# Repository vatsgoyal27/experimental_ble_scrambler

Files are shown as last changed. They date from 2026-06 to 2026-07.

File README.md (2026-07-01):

# BLE Experimental FHSS Test Platform

An experimental multi-radio platform built around the **nRF24L01+** for investigating frequency hopping behavior across the 2.4 GHz ISM band.

> **Disclaimer**
>
> This project is intended solely for laboratory testing, RF characterization, and educational purposes inside controlled environments. It is **not** intended for interfering with wireless communications or transmitting on frequencies in violation of local regulations.

---

## Overview

This board contains:

- Raspberry Pi Pico W controller
- Three independent nRF24L01+ transceivers
- Three external RF power amplifiers
- Individual RF filtering stages
- SMA antenna connectors for each RF chain

The objective is to create a configurable RF test platform capable of:

- Continuous carrier generation
- Channel sweeping
- Experimental frequency hopping
- Timing analysis
- Multi-radio synchronization
- BLE advertising channel experiments

---

## Hardware

### Controller

- Raspberry Pi Pico W
- 3.3 V logic

### RF Chain (×3)

Each RF path contains:

```
Pico SPI
      │
      ▼
nRF24L01+
      │
      ▼
2.45 GHz RF Filter
      │
      ▼
RF2401C Power Amplifier
      │
      ▼
2450LP14A100T Matching Network
      │
      ▼
SMA Connector
```

Each radio has:

- Dedicated 16 MHz crystal
- Local decoupling
- Separate CE control
- Shared SPI bus
- Individual RF output chain

---

## Schematic

The design currently consists of three identical RF sections driven from a common SPI interface.

Features include:

- SPI shared between all radios
- Independent CE lines
- External RF front-end
- Matching network
- Filtered antenna output

---

## Current Firmware

Current firmware configures an nRF24L01+ as:

- Transmitter mode
- Auto ACK disabled
- CRC disabled
- 2 Mbps
- Maximum PA level
- Constant carrier enabled

Example initialization:

```cpp
radio.setAutoAck(false);
radio.stopListening();
radio.setRetries(0,0);
radio.setPayloadSize(5);
radio.setAddressWidth(3);
radio.setPALevel(RF24_PA_MAX);
radio.setDataRate(RF24_2MBPS);
radio.setCRCLength(RF24_CRC_DISABLED);

radio.startConstCarrier(RF24_PA_MAX, channel);
```

---

## Experimental Channel Sweep

The current proof-of-concept changes the RF channel by repeatedly calling

```cpp
radio.setChannel(channel);
```

Example sweep:

```cpp
for (int i = 0; i < 79; i++)
{
    radio.setChannel(i);
}
```

---

## BLE Advertising Channel Test

The firmware also demonstrates hopping across the three BLE advertising channels.

```cpp
byte ble_channels[] =
{
    37,
    38,
    39
};

for(int i=0;i<3;i++)
{
    radio.setChannel(ble_channels[i]);
}
```

This serves as a simple experiment in channel switching behavior rather than implementing the Bluetooth Low Energy protocol itself.

---

## Project Goals

- [x] Multi-radio PCB
- [x] External PA integration
- [x] RF filtering
- [x] Basic firmware
- [x] Constant carrier generation
- [x] Channel switching
- [ ] Precise timing control
- [ ] Simultaneous multi-radio hopping
- [ ] DMA-driven SPI control
- [ ] RP2040 PIO synchronization
- [ ] Measurement using SDR
- [ ] Spectrum characterization

---

## Requirements

### Hardware

- Raspberry Pi Pico W
- 3 × nRF24L01+
- RF2401C
- 2450LP14A1002T filter
- 3.3 V power supply
- Antennas or appropriate RF loads for testing

### Software

- Arduino IDE
- RF24 library
- Raspberry Pi Pico board package

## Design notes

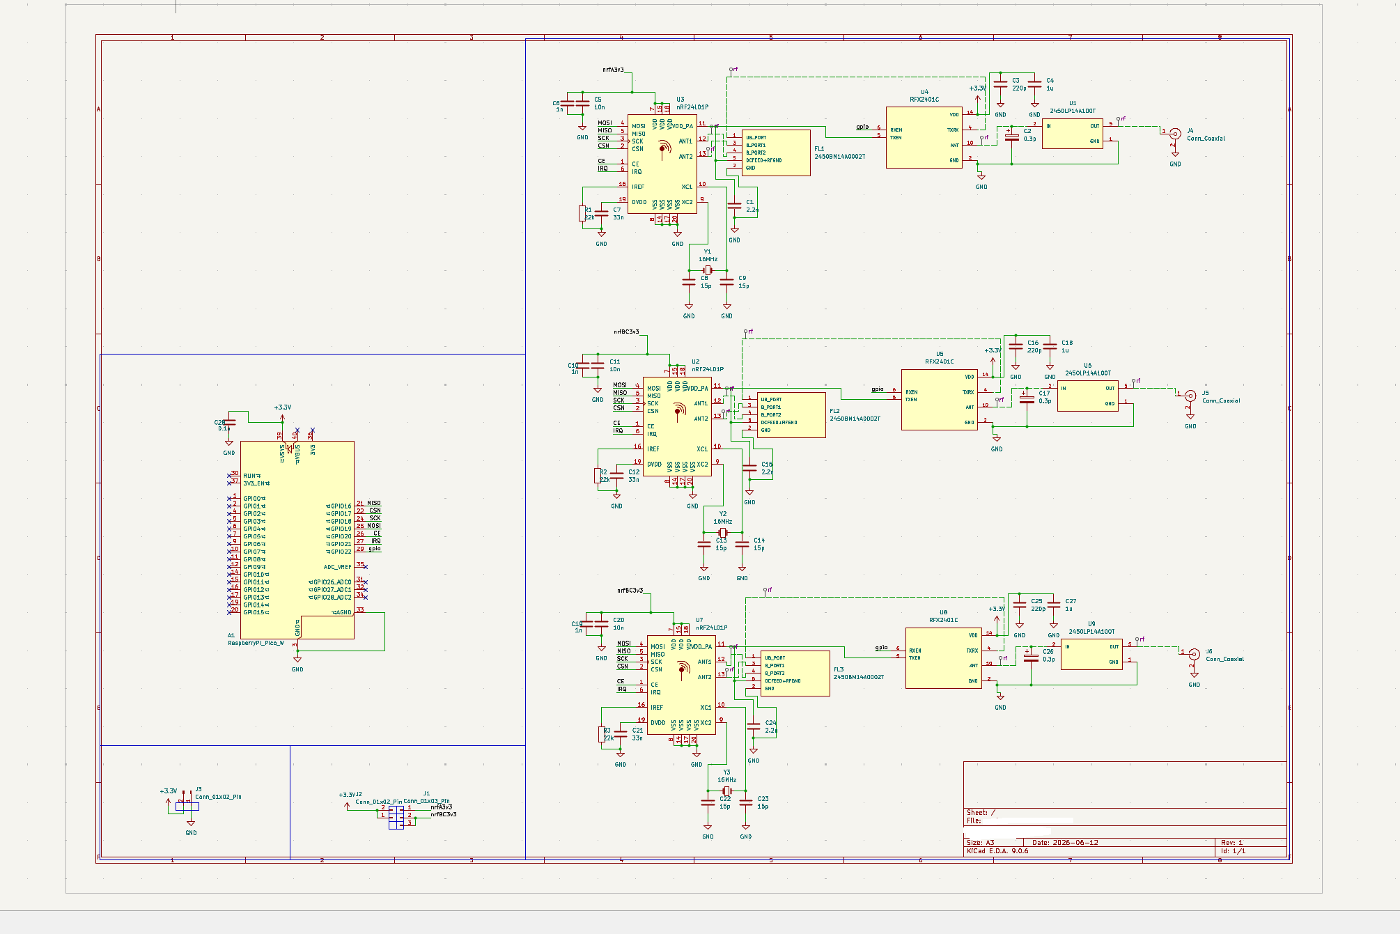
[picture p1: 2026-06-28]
ble_blocker_holder/schematic.png

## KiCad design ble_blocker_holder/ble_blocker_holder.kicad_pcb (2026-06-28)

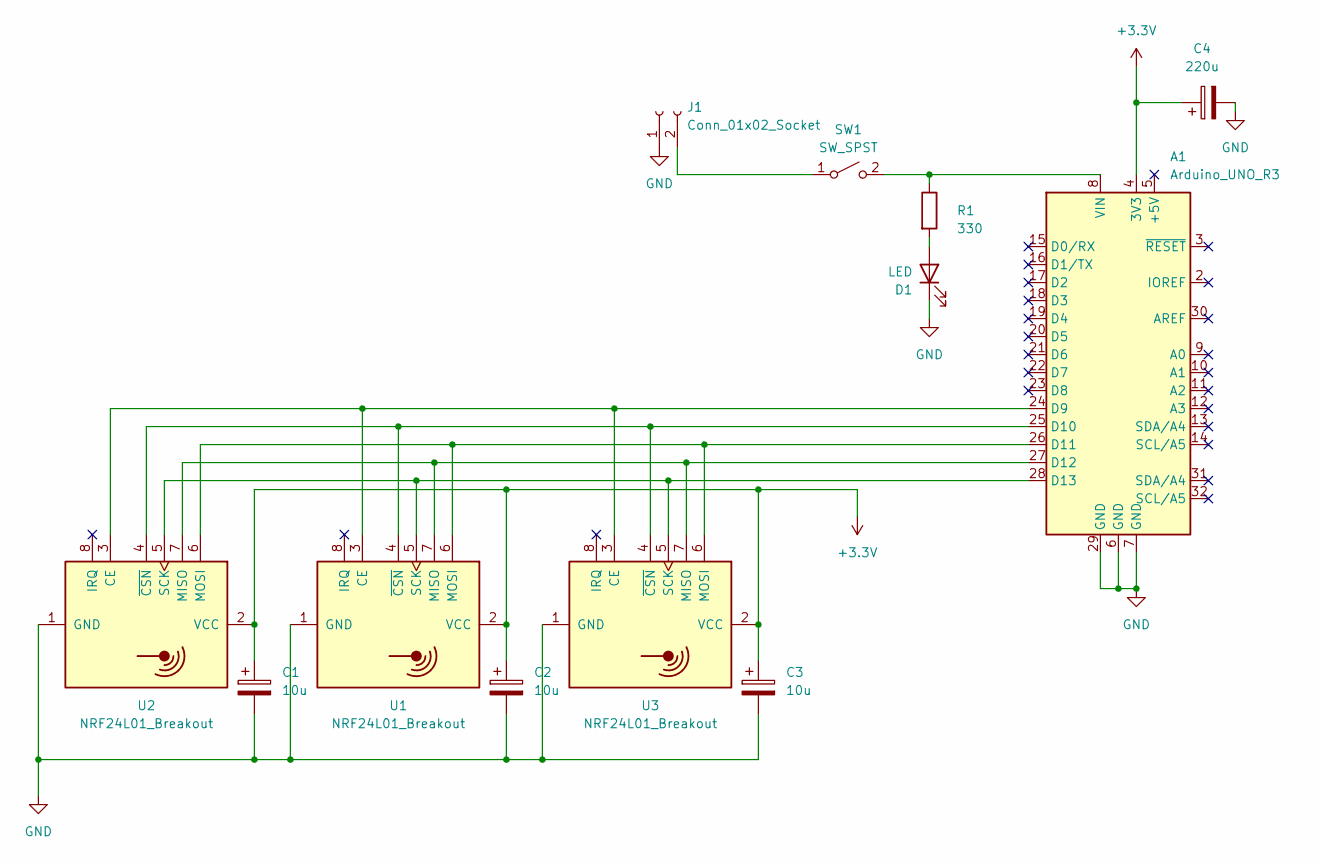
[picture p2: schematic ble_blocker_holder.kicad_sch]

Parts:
A1: Arduino_UNO_R3
C1, C2, C3: 10u; CP_Radial_D10.0mm_P2.50mm
C4: 220u; CP_Radial_D12.5mm_P5.00mm
D1: LED; LED_D5.0mm
J1: Conn_01x02_Socket; PinSocket_1x02_P2.54mm_Vertical
R1: 330; R_Axial_DIN0207_L6.3mm_D2.5mm_P7.62mm_Horizontal
SW1: SW_SPST; SW_DIP_SPSTx01_Slide_9.78x4.72mm_W7.62mm_P2.54mm
U1, U2, U3: NRF24L01_Breakout; nRF24L01_Breakout

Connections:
+3.3V: A1.4 (3V3), C1.1, C2.1, C3.1, C4.1, U1.2 (VCC), U2.2 (VCC), U3.2 (VCC)
GND: A1.6 (GND), A1.7 (GND), A1.29 (GND), C1.2, C2.2, C3.2, C4.2, D1.1 (K), J1.1, U1.1 (GND), U2.1 (GND), U3.1 (GND)
unnamed: A1.24 (D9), U1.3 (CE), U2.3 (CE), U3.3 (CE)
unnamed: A1.25 (D10), U1.4 (~CSN), U2.4 (~CSN), U3.4 (~CSN)
unnamed: A1.26 (D11), U1.6 (MOSI), U2.6 (MOSI), U3.6 (MOSI)
unnamed: A1.27 (D12), U1.7 (MISO), U2.7 (MISO), U3.7 (MISO)
unnamed: A1.28 (D13), U1.5 (SCK), U2.5 (SCK), U3.5 (SCK)
unnamed: A1.8 (VIN), R1.1, SW1.2 (B)
unnamed: D1.2 (A), R1.2
unnamed: J1.2, SW1.1 (A)

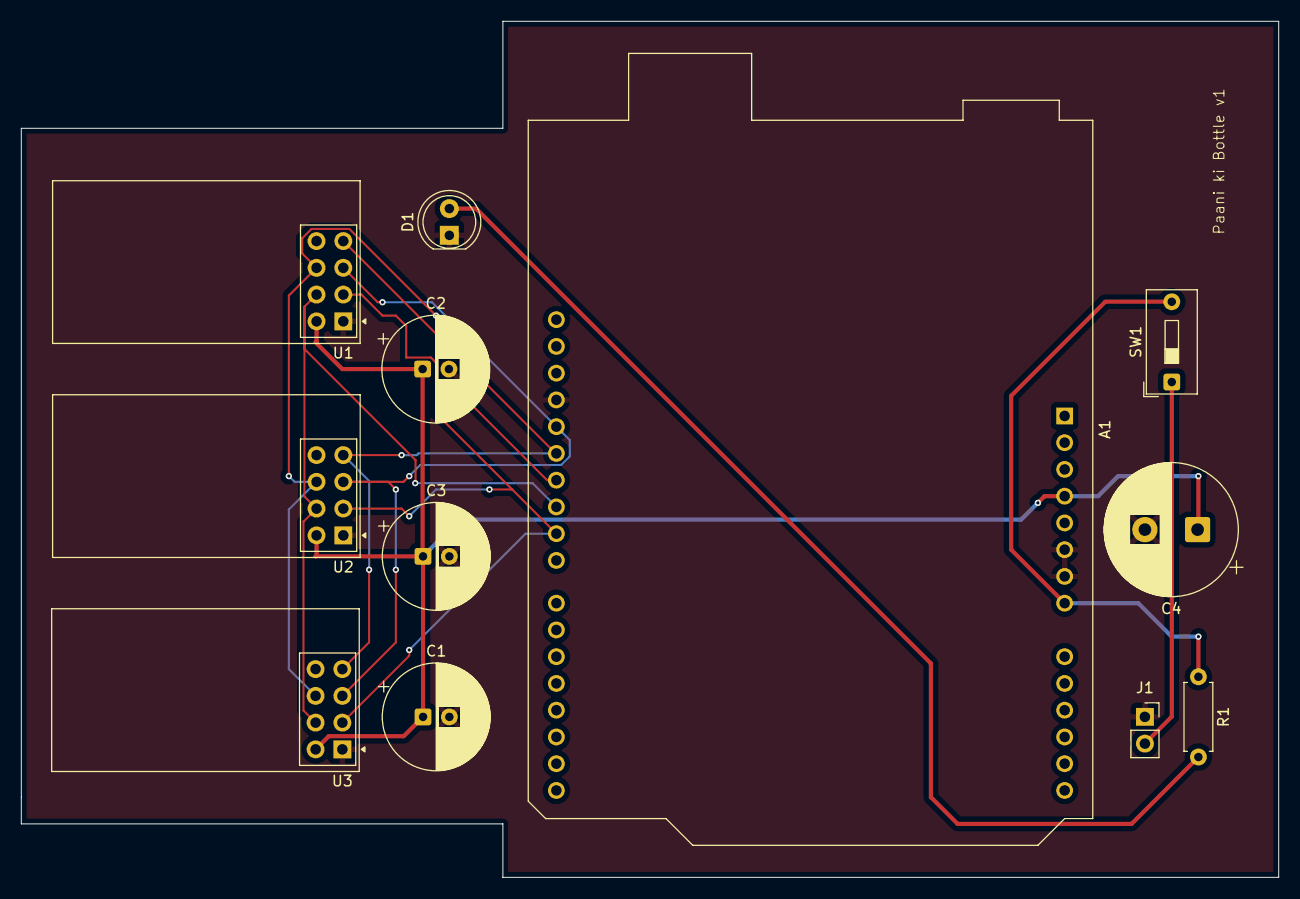
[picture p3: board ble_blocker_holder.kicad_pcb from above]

Board: 2 copper layers, 119.4 x 81.3 mm, 12 parts (0 on the bottom side), 10 nets.

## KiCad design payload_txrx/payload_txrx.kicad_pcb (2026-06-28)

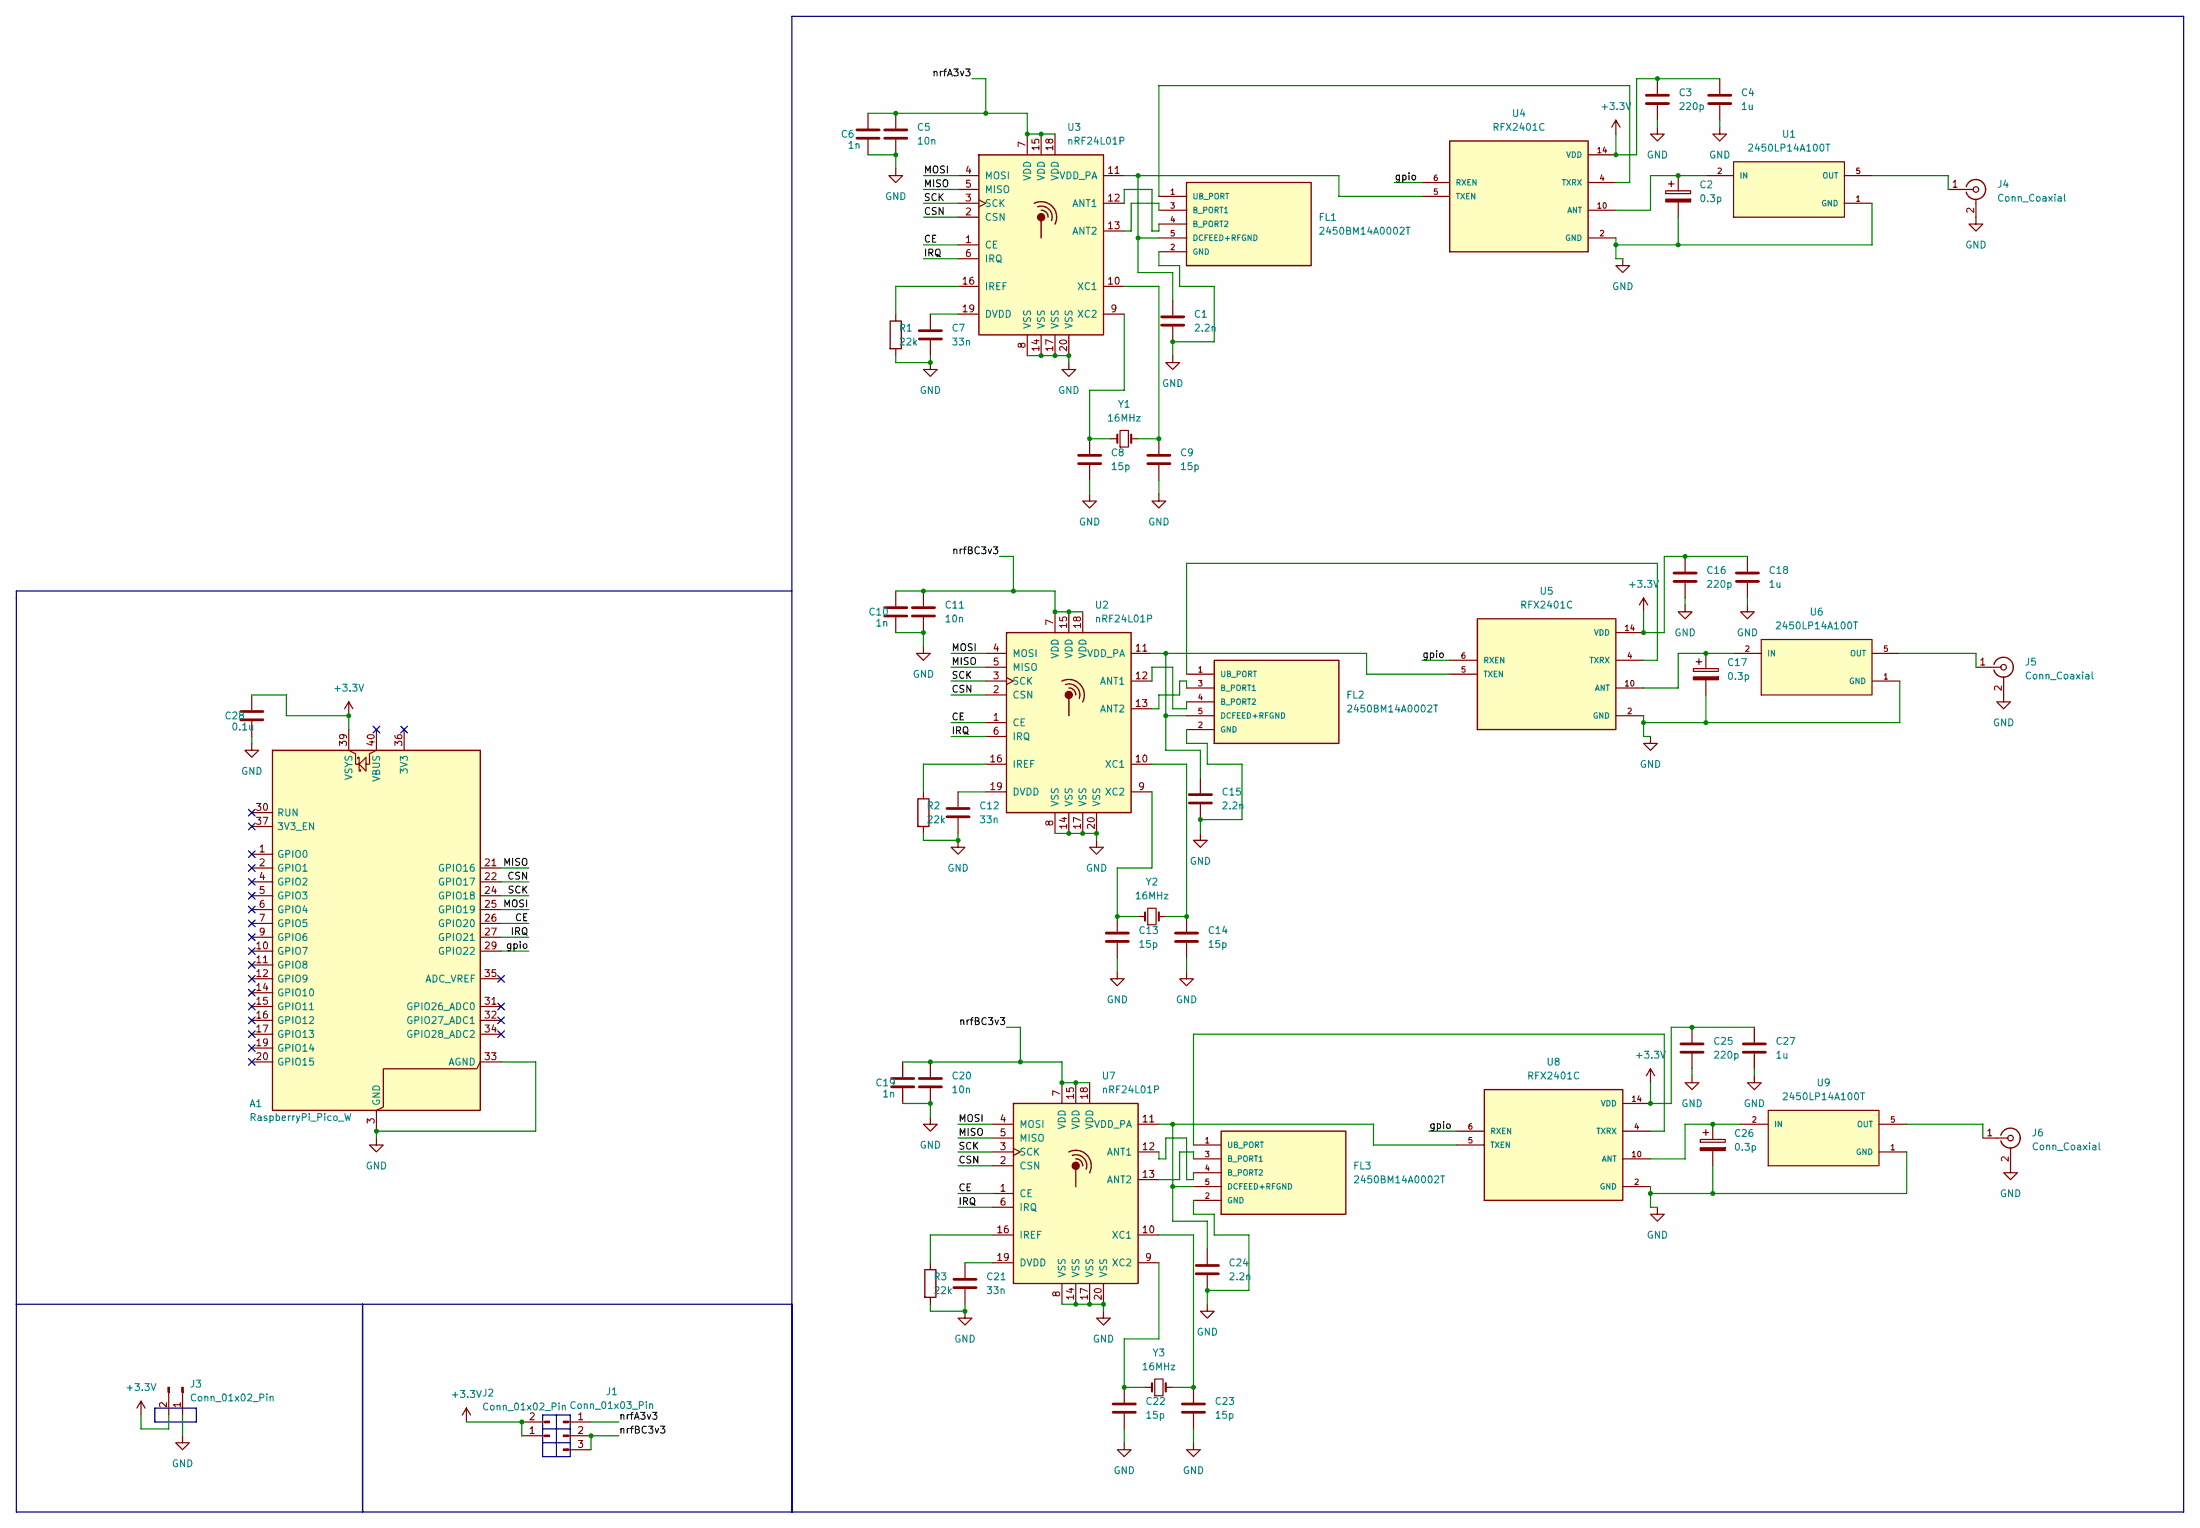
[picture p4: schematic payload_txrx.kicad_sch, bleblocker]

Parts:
A1: RaspberryPi_Pico_W; RaspberryPi_Pico_W_SMD_HandSolder
C1, C15, C24: 2.2n; C_0402_1005Metric
C2, C17, C26: 0.3p; C_0402_1005Metric
C3, C16, C25: 220p; C_0402_1005Metric
C4, C18, C27: 1u; C_0402_1005Metric
C5, C11, C20: 10n; C_0402_1005Metric
C6, C10, C19: 1n; C_0402_1005Metric
C7, C12, C21: 33n; C_0402_1005Metric
C8, C9, C13, C14, C22, C23: 15p; C_0402_1005Metric
C28: 0.1u; C_0402_1005Metric
FL1, FL2, FL3: 2450BM14A0002T; FIL_2450BM14A0002T
J1: Conn_01x03_Pin; PinHeader_1x03_P1.27mm_Vertical
J2, J3: Conn_01x02_Pin; PinHeader_1x02_P1.27mm_Vertical
J4, J5, J6: Conn_Coaxial; SMA_Molex_73251-2120_EdgeMount_Horizontal
R1, R2, R3: 22k; R_0402_1005Metric
U1, U6, U9: 2450LP14A100T; ICCAF50P160X80X70-6N; PARTREV 06/23/03
U2, U3, U7: nRF24L01P; QFN-20-1EP_4x4mm_P0.5mm_EP2.5x2.5mm
U4, U5, U8: RFX2401C; QFN50P300X300X60-17N
Y1, Y2, Y3: 16MHz; Crystal_SMD_3225-4Pin_3.2x2.5mm

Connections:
+3.3V: A1.39 (VSYS), C3.1, C4.1, C16.1, C18.1, C25.1, C27.1, C28.1, J2.1, J2.2, J3.2, U4.14 (VDD), U4.16 (VDD), U5.14 (VDD), U5.16 (VDD), U8.14 (VDD), U8.16 (VDD)
/CE: A1.26 (GPIO20), U2.1 (CE), U3.1 (CE), U7.1 (CE)
/CSN: A1.22 (GPIO17), U2.2 (CSN), U3.2 (CSN), U7.2 (CSN)
/IRQ: A1.27 (GPIO21), U2.6 (IRQ), U3.6 (IRQ), U7.6 (IRQ)
/MISO: A1.21 (GPIO16), U2.5 (MISO), U3.5 (MISO), U7.5 (MISO)
/MOSI: A1.25 (GPIO19), U2.4 (MOSI), U3.4 (MOSI), U7.4 (MOSI)
/SCK: A1.24 (GPIO18), U2.3 (SCK), U3.3 (SCK), U7.3 (SCK)
/gpio: A1.29 (GPIO22), U4.6 (RXEN), U5.6 (RXEN), U8.6 (RXEN)
/nrfA3v3: C5.1, C6.1, J1.1, U3.7 (VDD), U3.15 (VDD), U3.18 (VDD)
/nrfBC3v3: C10.1, C11.1, C19.1, C20.1, J1.2, J1.3, U2.7 (VDD), U2.15 (VDD), U2.18 (VDD), U7.7 (VDD), U7.15 (VDD), U7.18 (VDD)
GND: A1.3 (GND), A1.8 (GND), A1.13 (GND), A1.18 (GND), A1.23 (GND), A1.28 (GND), A1.33 (AGND), A1.38 (GND), C1.2, C2.2, C3.2, C4.2, C5.2, C6.2, C7.2, C8.2, C9.2, C10.2, C11.2, C12.2, C13.2, C14.2, C15.2, C16.2, C17.2, C18.2, C19.2, C20.2, C21.2, C22.2, C23.2, C24.2, C25.2, C26.2, C27.2, C28.2, FL1.2 (GND), FL2.2 (GND), FL3.2 (GND), J3.1, J4.2 (Ext), J5.2 (Ext), J6.2 (Ext), R1.2, R2.2, R3.2, U1.1 (GND), U1.3 (GND), U1.4 (GND), U1.6 (GND), U2.8 (VSS), U2.14 (VSS), U2.17 (VSS), U2.20 (VSS), U3.8 (VSS), U3.14 (VSS), U3.17 (VSS), U3.20 (VSS), U4.2 (GND), U4.3 (GND), U4.8 (GND), U4.9 (GND), U4.11 (GND), U4.17 (GND), U5.2 (GND), U5.3 (GND), U5.8 (GND), U5.9 (GND), U5.11 (GND), U5.17 (GND), U6.1 (GND), U6.3 (GND), U6.4 (GND), U6.6 (GND), U7.8 (VSS), U7.14 (VSS), U7.17 (VSS), U7.20 (VSS), U8.2 (GND), U8.3 (GND), U8.8 (GND), U8.9 (GND), U8.11 (GND), U8.17 (GND), U9.1 (GND), U9.3 (GND), U9.4 (GND), U9.6 (GND)
unnamed: FL1.3 (B_PORT1), U3.13 (ANT2)
unnamed: FL1.4 (B_PORT2), U3.12 (ANT1)
unnamed: C1.1, FL1.5 (DCFEED+RFGND), U3.11 (VDD_PA), U4.5 (TXEN)
unnamed: FL1.1 (UB_PORT), U4.4 (TXRX)
unnamed: FL2.3 (B_PORT1), U2.13 (ANT2)
unnamed: FL2.4 (B_PORT2), U2.12 (ANT1)
unnamed: C15.1, FL2.5 (DCFEED+RFGND), U2.11 (VDD_PA), U5.5 (TXEN)
unnamed: FL2.1 (UB_PORT), U5.4 (TXRX)
unnamed: FL3.3 (B_PORT1), U7.13 (ANT2)
unnamed: FL3.4 (B_PORT2), U7.12 (ANT1)
unnamed: C24.1, FL3.5 (DCFEED+RFGND), U7.11 (VDD_PA), U8.5 (TXEN)
unnamed: FL3.1 (UB_PORT), U8.4 (TXRX)
unnamed: J4.1 (In), U1.5 (OUT)
unnamed: J5.1 (In), U6.5 (OUT)
unnamed: J6.1 (In), U9.5 (OUT)
unnamed: C2.1, U1.2 (IN), U4.10 (ANT)
unnamed: C12.1, U2.19 (DVDD)
unnamed: R2.1, U2.16 (IREF)
unnamed: C14.1, U2.10 (XC1), Y2.2
unnamed: C13.1, U2.9 (XC2), Y2.1
unnamed: C7.1, U3.19 (DVDD)
unnamed: R1.1, U3.16 (IREF)
unnamed: C9.1, U3.10 (XC1), Y1.2
unnamed: C8.1, U3.9 (XC2), Y1.1
unnamed: C17.1, U5.10 (ANT), U6.2 (IN)
unnamed: C21.1, U7.19 (DVDD)
unnamed: R3.1, U7.16 (IREF)
unnamed: C23.1, U7.10 (XC1), Y3.2
unnamed: C22.1, U7.9 (XC2), Y3.1
unnamed: C26.1, U8.10 (ANT), U9.2 (IN)

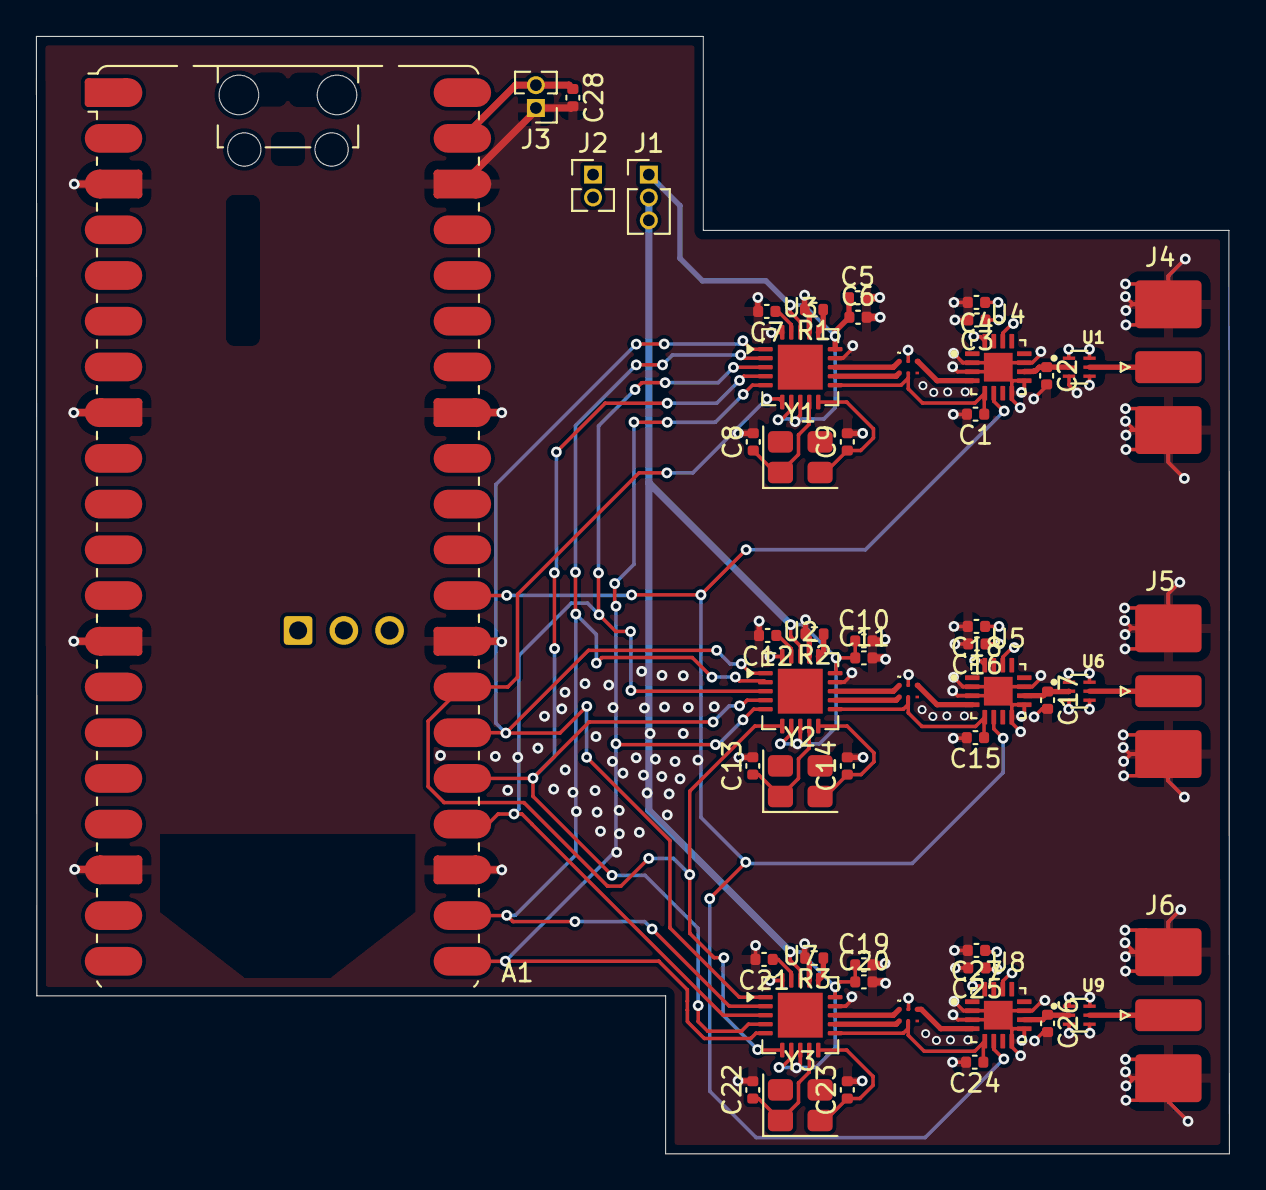
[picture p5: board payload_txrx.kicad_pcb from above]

Board: 4 copper layers, 66.3 x 62.1 mm, 53 parts (0 on the bottom side), 41 nets.

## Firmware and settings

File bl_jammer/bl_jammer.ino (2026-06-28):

/*
* Arduino Uno with nRF24L01 
*                
* by jbalagiya
* 
* Library: TMRh20/RF24, https://github.com/tmrh20/RF24/
*/
#include "RF24.h"

RF24 radio(9, 10); // CE, CSN pins for NRF24L01

byte i = 45;  // Initial channel for nRF24L01
unsigned int flag = 0;  // Flag to control channel hopping direction

void setup() {
  Serial.begin(115200); // Initialize serial communication
 if (radio.begin()) {
    delay(200);
    Serial.println("Radio Initialized!");
    radio.setAutoAck(false);       // Disable automatic acknowledgment
    radio.stopListening();         // Set to transmitter mode
    radio.setRetries(0, 0);        // Disable retries
    radio.setPayloadSize(5);       // Set payload size to 5 bytes
    radio.setAddressWidth(3);      // Set address width to 3 bytes
    radio.setPALevel(RF24_PA_MAX, true); // Set power amplification to maximum
    radio.setDataRate(RF24_2MBPS); // Set data rate to 2 Mbps
    radio.setCRCLength(RF24_CRC_DISABLED); // Disable CRC
    radio.printPrettyDetails();    // Print radio details for debugging
    radio.startConstCarrier(RF24_PA_MAX, i);  // Start continuous carrier with specified channel
  } else {
    Serial.println("Failed to initialize radio!");
  }
}

void loop() {
  // Sweep through all channels (0 to 79)
   for (int i = 0; i < 79; i++) {
    radio.setChannel(i);
   }
    // Specifically target BLE advertising channels (37, 38, 39)
  byte ble_channels[] = {37, 38, 39};
  for (int j = 0; j < 3; j++) {
    radio.setChannel(ble_channels[j]);
  }
}

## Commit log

2026-06-28 project items
    code is for arduino and the board is for pico, will adapt code for the pico soon
    [payload_txrx.kicad_pcb, payload_txrx.kicad_sch]
2026-06-28 original attempt
    an older pcb using aughter boards to save on rf planning
    [ble_blocker_holder.kicad_pcb, ble_blocker_holder.kicad_sch]
2026-07-01 Add README for BLE FHSS Test Platform
    Added detailed README for BLE Experimental FHSS Test Platform, including project overview, hardware specifications, schematic, current firmware, experimental features, project goals, and requirements.
